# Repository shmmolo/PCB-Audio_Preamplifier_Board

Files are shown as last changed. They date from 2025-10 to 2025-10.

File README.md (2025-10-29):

# Audio Preamplifier Board (Active Baxandall)

A stereo audio preamplifier with active Baxandall tone control and NE5532 op-amp for low-noise, high-fidelity performance.

## Features
- Stereo AUX input (3.5 mm jack)
- Active Baxandall bass and treble control
- ±12 V supply using LM317/LM337 power source
- Dual-ganged potentiometers for Bass, Treble, and Volume
- NE5532 dual op-amp for both channels

## Performance
| Parameter | Typical Value |
|---|---|
| Bass Boost/Cut | ±15 dB @ 100 Hz |
| Treble Boost/Cut | ±14 dB @ 10 kHz |
| Slew Rate (NE5532) | 9 V/µs |
| THD | 0.0005 % |
| Bandwidth | 10 MHz |
| Supply Voltage | ±12 V |

## Applications
- Stereo preamp or tone control
- Signal conditioning for amplifiers
- DIY audio and analog circuit experimentation

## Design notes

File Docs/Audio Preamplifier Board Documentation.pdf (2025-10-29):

# Audio Preamplifier Board

## Overview

This is a stereo audio preamplifier board featuring an active Baxandall tone control stage for both left and right channels, followed by a dual-channel volume control. The circuit is based on the NE5532 low-noise dual op-amp, operating on a ±12 V dual-rail supply, providing clean and accurate amplification for line-level audio inputs such as AUX sources.

## Key Features

- Input: Stereo AUX (3.5 mm audio jack)
- Tone Control: Active Baxandall configuration (bass + treble boost/cut)
- Amplifier IC: NE5532 dual operational amplifier
- Supply Voltage: ±12 V regulated (from external or previous dual power supply board)
- Controls:
- Dual-ganged potentiometers for Bass, Treble, and Volume, ensuring both channels adjust simultaneously
- Output: Dual RCA or pin header for left and right channels

## Circuit Description

### 1. Baxandall Tone Control

- The active Baxandall network provides symmetrical boost and cut for low and high frequencies by varying feedback around the op-amp.
- Instead of merely attenuating frequencies (as in passive designs), the active configuration amplifies desired ranges, maintaining a flat overall gain near 0 dB when controls are centered.

Typical Frequency Response (approx. values based on chosen R and C):
- Bass control (R = 10 kΩ, C = 22 nF): cutoff ≈ 250 Hz
- Treble control (R = 3.3 kΩ, C = 1.8 nF): cutoff ≈ 3 kHz

Boost/Attenuation Levels (estimated):
- Bass: ±15 dB @ 100 Hz
- Treble: ±14 dB @ 10 kHz

(These values are derived from tone-control transfer functions with op-amp gain of ~20 dB and the given R–C network.)

### 2. NE5532 Operational Amplifier

- Slew Rate: 9 V/µs → suitable for high-frequency, low-distortion audio
- Input Noise Density: 5 nV/√Hz → low background noise
- Gain Bandwidth Product: 10 MHz
- Typical THD: 0.0005 % → audiophile-grade performance
- Operates reliably from ±5 V to ±15 V rails, here biased at ±12 V for best dynamic range.

### 3. Volume Control Stage

- Final dual-ganged potentiometer (RV3) acts as a master stereo volume control, placed after the tone stages.
- Each channel’s wiper feeds the final output coupling capacitor (4.7 µF), ensuring DC blocking and preventing bias shifts to subsequent amplifier stages.

## PCB Design

- 2-Layer PCB with separated analog ground and power planes to minimize noise coupling.
- Short feedback traces and star-ground topology for low-hum operation.
- Positioned potentiometers at board edge for easy access on a front panel.
- Designed for integration with ±12 V dual power supply board.

## Applications

- Stereo preamplifier for DIY or powered speakers
- Audio equalization for small amplifier systems
- Educational analog electronics project (tone-control design)
- Signal conditioning for class-D or AB power stages

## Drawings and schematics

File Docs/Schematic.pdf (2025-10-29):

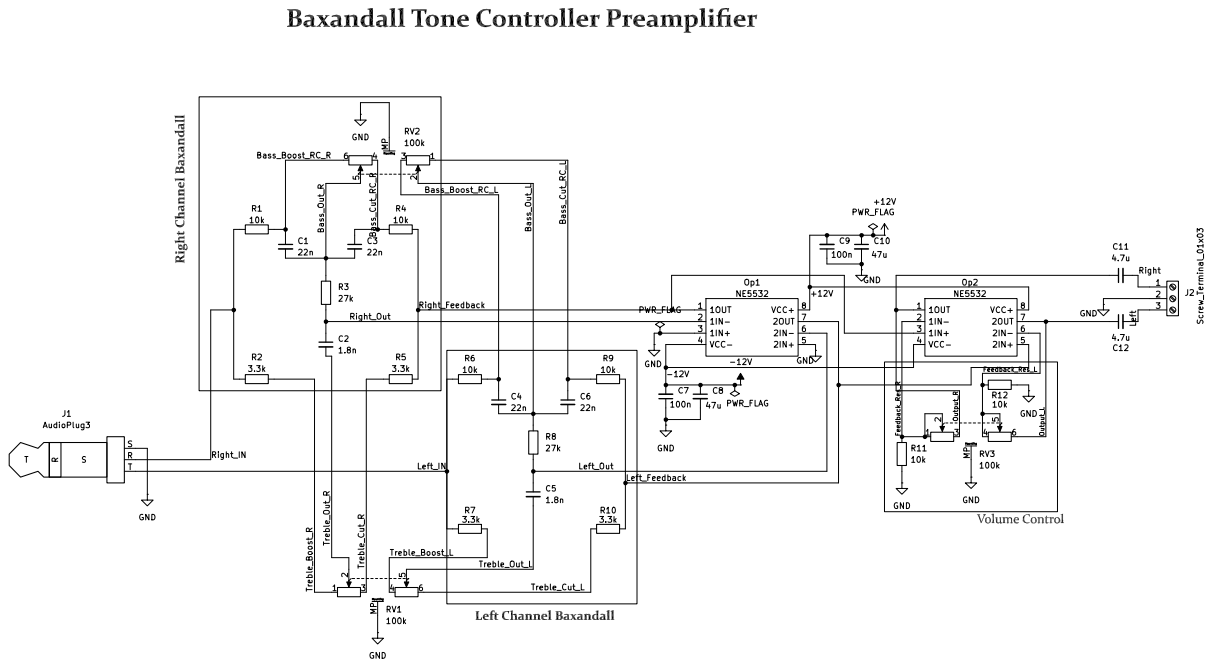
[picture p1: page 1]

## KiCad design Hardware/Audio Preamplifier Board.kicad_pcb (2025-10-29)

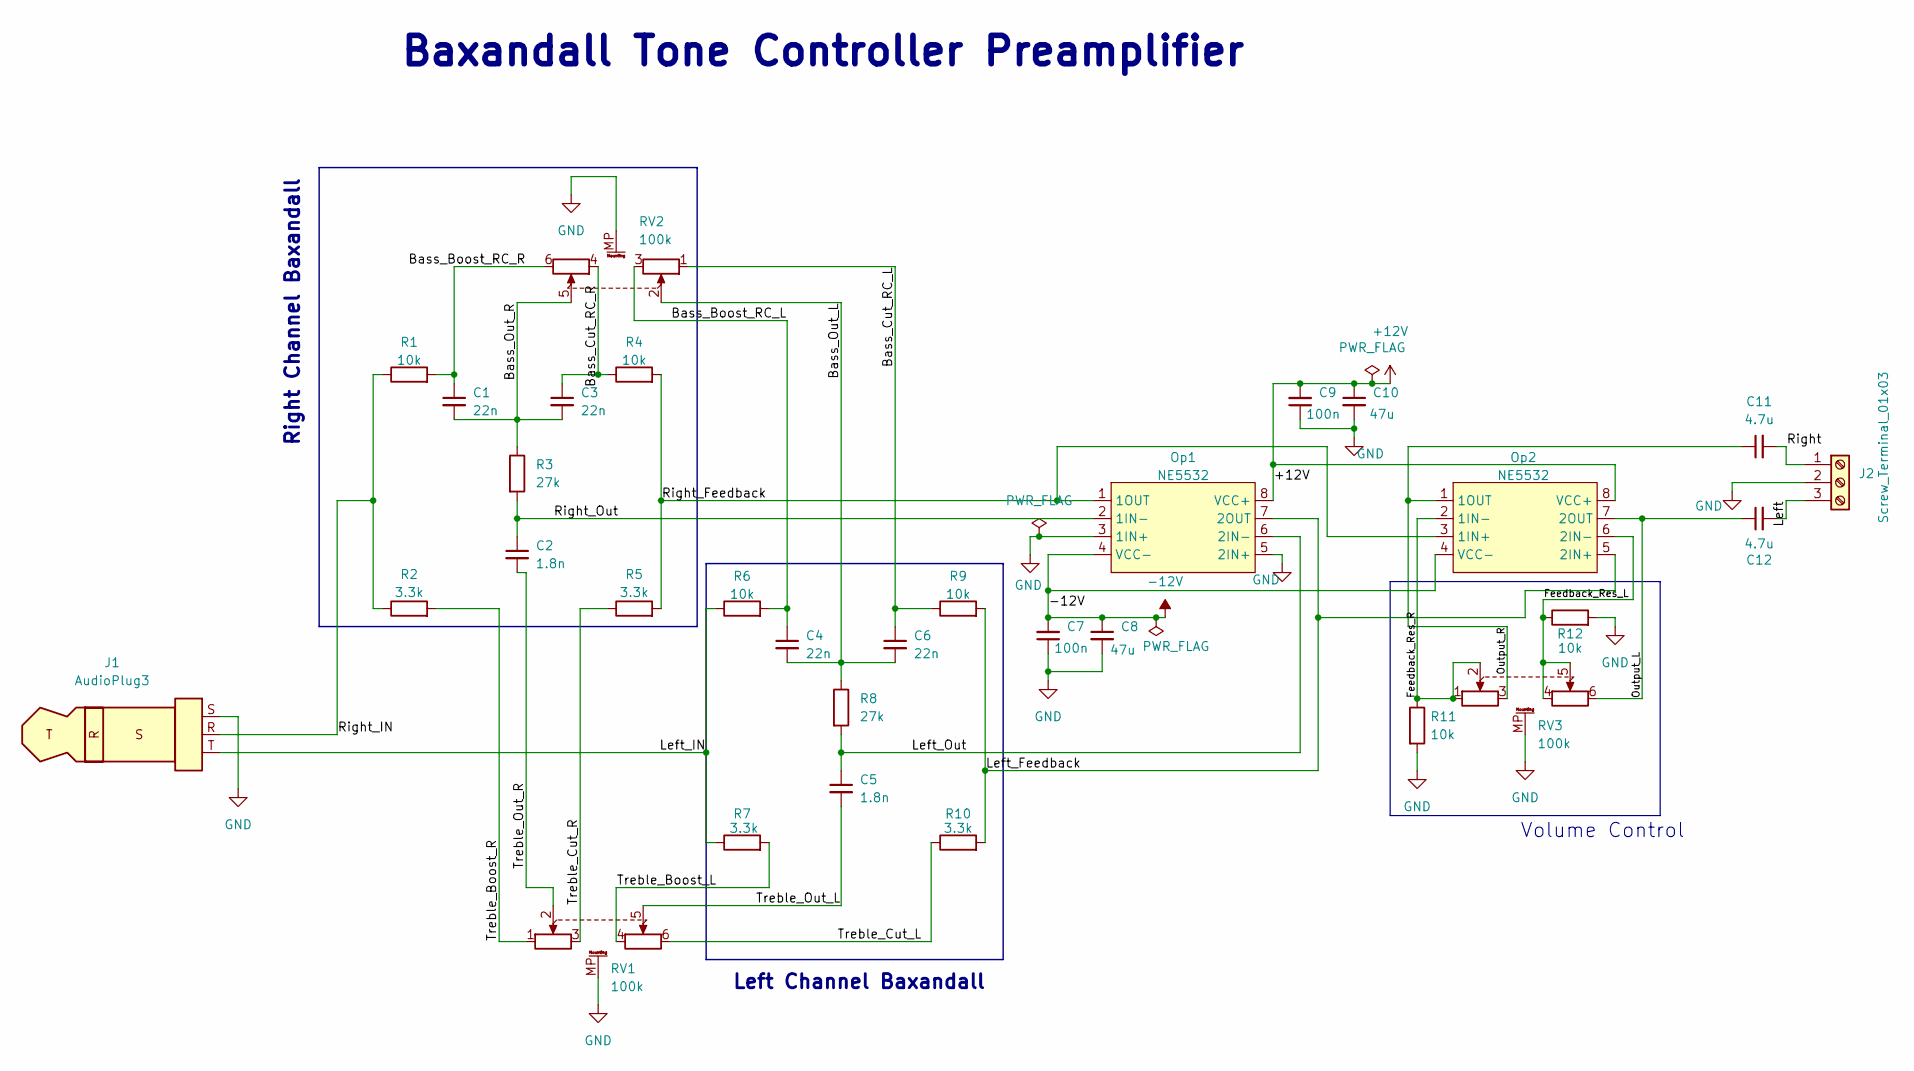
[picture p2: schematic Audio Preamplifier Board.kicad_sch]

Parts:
C1, C3, C4, C6: 22n; C_Disc_D4.7mm_W2.5mm_P5.00mm
C2, C5: 1.8n; C_Disc_D4.7mm_W2.5mm_P5.00mm
C7, C9: 100n; C_Disc_D4.7mm_W2.5mm_P5.00mm
C8, C10: 47u; CP_Radial_D8.0mm_P3.50mm
C11, C12: 4.7u; CP_Radial_D8.0mm_P3.50mm
J1: AudioPlug3; Jack_3.5mm_CUI_SJ1-3533NG_Horizontal
J2: Screw_Terminal_01x03; TerminalBlock_Phoenix_MKDS-1,5-3-5.08_1x03_P5.08mm_Horizont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
Op1, Op2: NE5532
R1, R4, R6, R9, R11, R12: 10k; R_Axial_DIN0207_L6.3mm_D2.5mm_P7.62mm_Horizontal
R2, R5, R7, R10: 3.3k; R_Axial_DIN0207_L6.3mm_D2.5mm_P7.62mm_Horizontal
R3, R8: 27k; R_Axial_DIN0207_L6.3mm_D2.5mm_P7.62mm_Horizontal
RV1, RV2, RV3: 100k; Potentiometer_Alps_RK163_Dual_Horizontal

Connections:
+12V: C9.2, C10.1, Op1.8 (VCC+), Op2.8 (VCC+)
-12V: C7.2, C8.1, Op1.4 (VCC-), Op2.4 (VCC-)
/Bass_Boost_RC_L: C4.1, R6.2, RV2.3
/Bass_Boost_RC_R: C1.1, R1.2, RV2.6
/Bass_Cut_RC_L: C6.1, R9.1, RV2.1
/Bass_Cut_RC_R: C3.1, R4.1, RV2.4
/Bass_Out_L: C4.2, C6.2, R8.1, RV2.2
/Bass_Out_R: C1.2, C3.2, R3.1, RV2.5
/Feedback_Res_L: Op2.6 (2IN-), R12.1, RV3.4, RV3.5
/Feedback_Res_R: Op2.2 (1IN-), R11.1, RV3.1, RV3.2
/Left: C12.2, J2.3
/Left_Feedback: Op1.7 (2OUT), Op2.5 (2IN+), R9.2, R10.2
/Left_IN: J1.T, R6.1, R7.1
/Left_Out: C5.1, Op1.6 (2IN-), R8.2
/Output_L: C12.1, Op2.7 (2OUT), RV3.6
/Output_R: C11.1, Op2.1 (1OUT), RV3.3
/Right: C11.2, J2.1
/Right_Feedback: Op1.1 (1OUT), Op2.3 (1IN+), R4.2, R5.2
/Right_IN: J1.R, R1.1, R2.1
/Right_Out: C2.1, Op1.2 (1IN-), R3.2
/Treble_Boost_L: R7.2, RV1.4
/Treble_Boost_R: R2.2, RV1.1
/Treble_Cut_L: R10.1, RV1.6
/Treble_Cut_R: R5.1, RV1.3
/Treble_Out_L: C5.2, RV1.5
/Treble_Out_R: C2.2, RV1.2
GND: C7.1, C8.2, C9.1, C10.2, J1.S, J2.2, Op1.3 (1IN+), Op1.5 (2IN+), R11.2, R12.2, RV1.MP (MountPin), RV2.MP (MountPin), RV3.MP (MountPin)

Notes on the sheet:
Left Channel Baxandall
Right Channel Baxandall
Baxandall Tone Controller Preamplifier
Volume Control

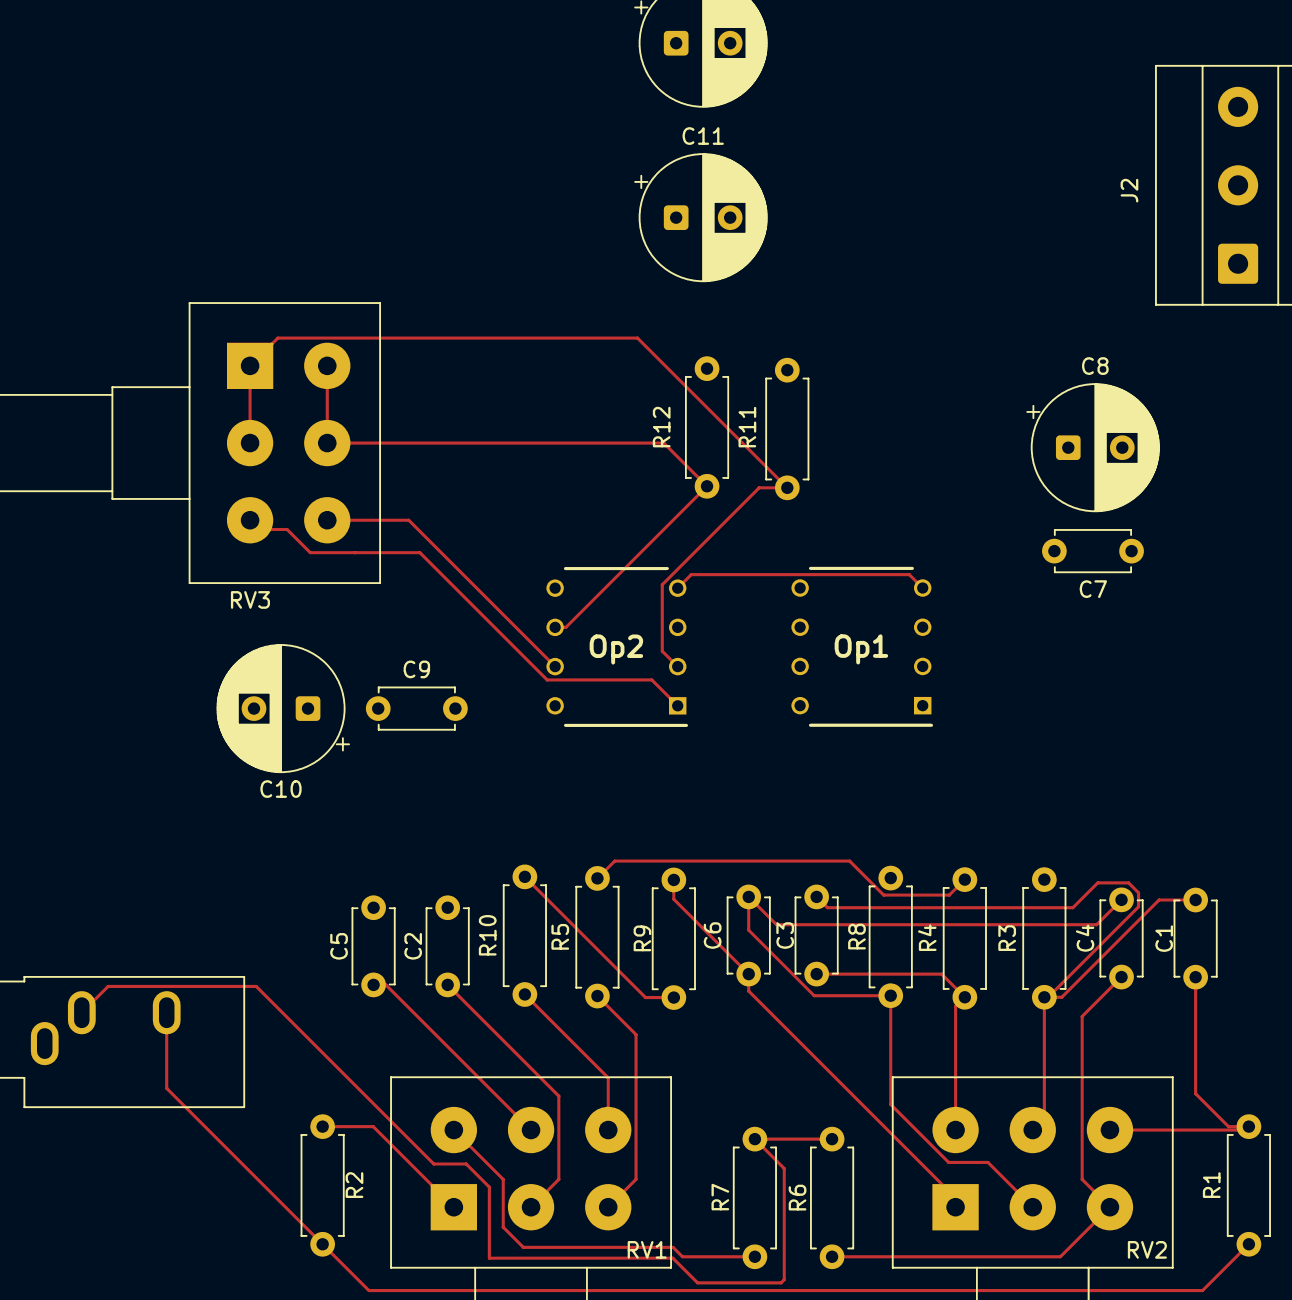
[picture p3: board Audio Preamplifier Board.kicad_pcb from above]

Board: 2 copper layers, 31 parts (0 on the bottom side), 27 nets.
